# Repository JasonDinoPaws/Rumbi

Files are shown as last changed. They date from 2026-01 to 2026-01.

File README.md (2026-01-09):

This is version 1.0 of Rumbi.

Rumbi comes from the game A hat in time with the soul perpose to give some life to the spaceship. This is trying to give it more of a perpose. This version is slightly buggy since the all the leds need to be ran on sudo but the audio libary will sometimes work.

# Parts
- Pi - https://www.amazon.com/dp/B0899VXM8F?ref=ppx_yo2ov_dt_b_fed_asin_title
- Pi Camera - https://www.amazon.com/dp/B01ER2SKFS?ref=ppx_yo2ov_dt_b_fed_asin_title
- Gearbox Motors - https://www.amazon.com/dp/B098Q1BCX5?ref=ppx_yo2ov_dt_b_fed_asin_title
- Led Strip - https://www.amazon.com/dp/B01MG49QKD?ref=ppx_yo2ov_dt_b_fed_asin_title
- Led Matrix x2 - https://www.amazon.com/dp/B0DGT58PDH?ref=ppx_yo2ov_dt_b_fed_asin_title

# Printing
## Bottom 
- Bottom.stl - 7.5in x 7.5in X 1in
- Ball.stl x3 - .875in

## Motor
- Wheel.stl - Wheel
- Motor Holder.stl - It sits in the center of bottom.stl
- MotorRoof.stl - trying its best to hold the gear motors from comming up
- Lifter and cover.stl - To hold the MotorRoof.stl to Motor Holder.stl 

## Other Interior objects
- Pi.stl - Degined for a Pi 4 and sits on the Lifter and cover.stl
- Battery holder.stl - Combined with x4 Item connectors.stl to connect to Pi.stl
- Item Cover.stl to sit ontop of Battery holder.stl connected by Roof conecters.stl x4
- Amplafiyer.stl, Button.stl, Speaker holder.stl - to fill the space in Item Cover.stl in the order of Amplafiyer.stl, Button.stl, Speaker holder.stl 

## Top
- Top.stl x2 - It's ment to hold the top together with a tight fit, and kindof the walls
- Top exterdor.stl - How the Top.stl stays together
- Innter Top.stl - slides on the Top exterdor.stl
- Cap.stl - to sit on a button  that clsoes the the hold in the Innter Top.stl

## Walls - all are 4.85 in tall
- Fan.stl - the back
- gray.stl x2 - next to fan.stl
- endofblack.stl x2 - next to the gray.stl
- face-L - for the left side of the face
- face-R - for the right side of the face

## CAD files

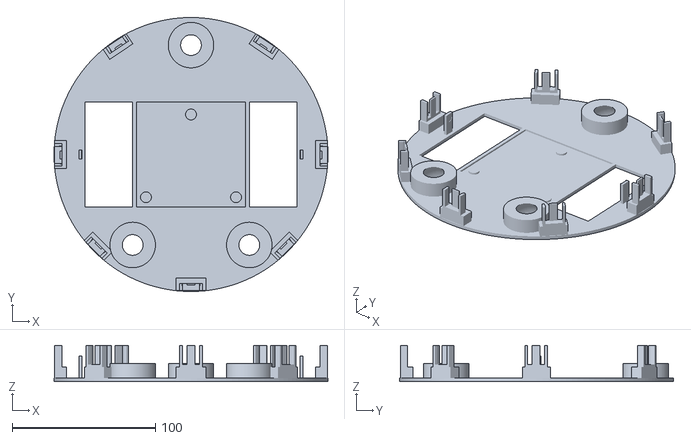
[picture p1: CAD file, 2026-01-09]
Stls/Bottom/Bottom.stl
191.3 x 191.3 x 25.4

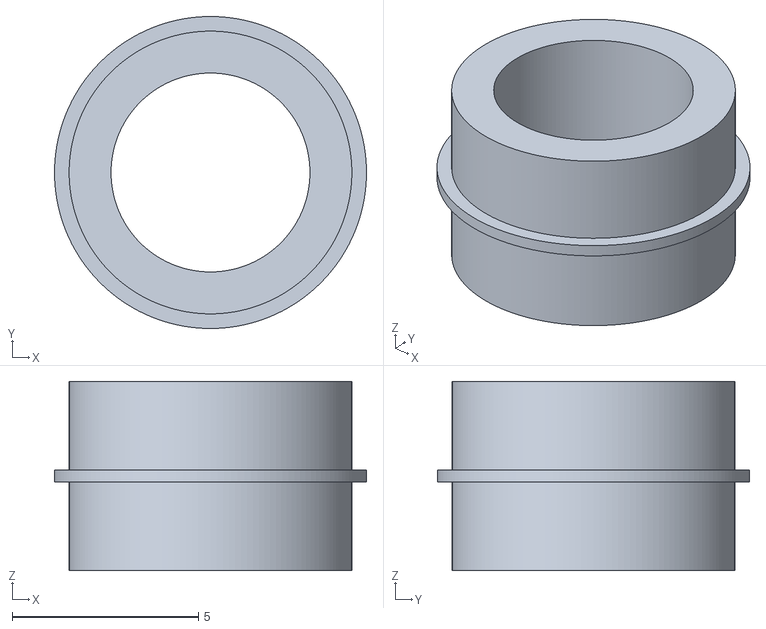
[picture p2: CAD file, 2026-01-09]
Stls/Item connectors.stl
8.38 x 8.38 x 5.08

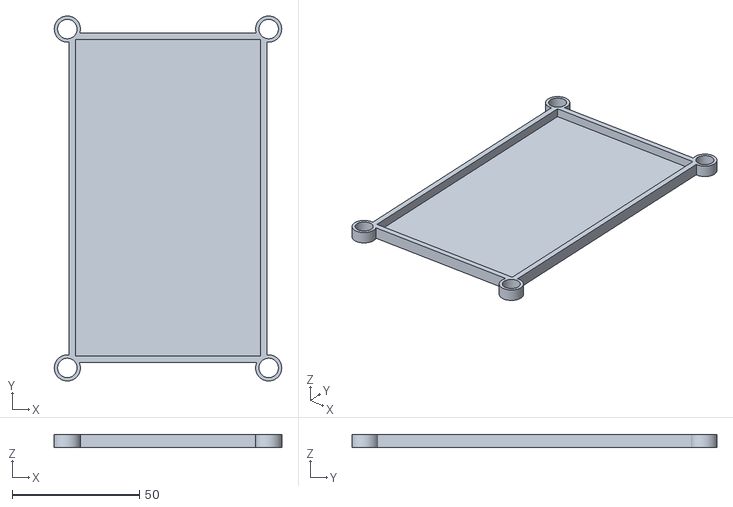
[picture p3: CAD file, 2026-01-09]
Stls/Item Holder/Item Cover.stl
89.3 x 143.3 x 5.08

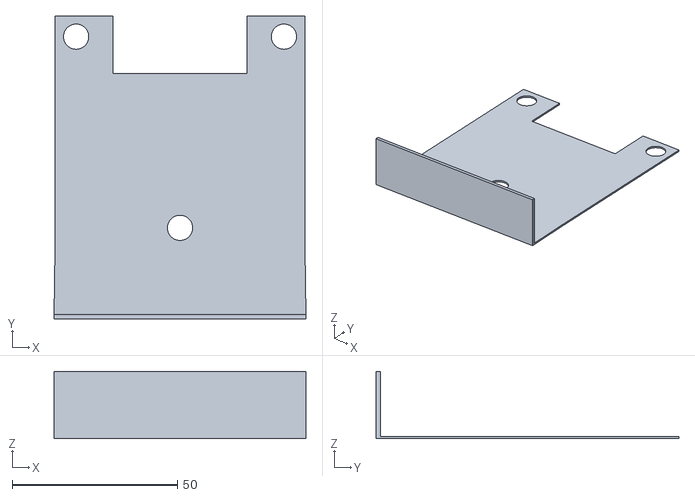
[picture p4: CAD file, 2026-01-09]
Stls/Motor/MotorRoof.stl
76.2 x 91.6 x 20.3

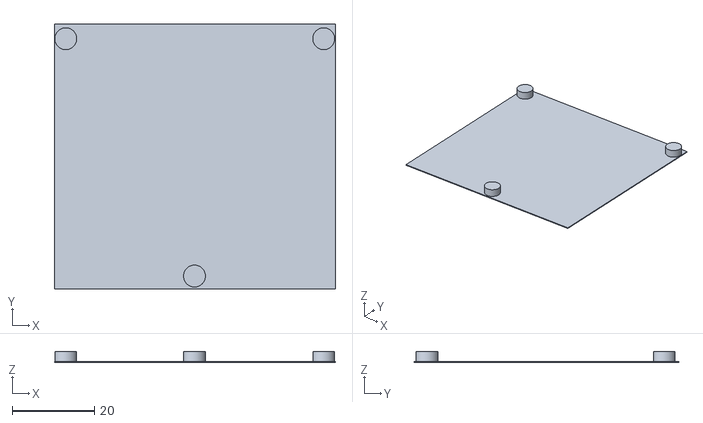
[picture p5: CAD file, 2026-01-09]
Stls/Pi and battery/Defalt big cap.stl
68.5 x 64.5 x 2.79

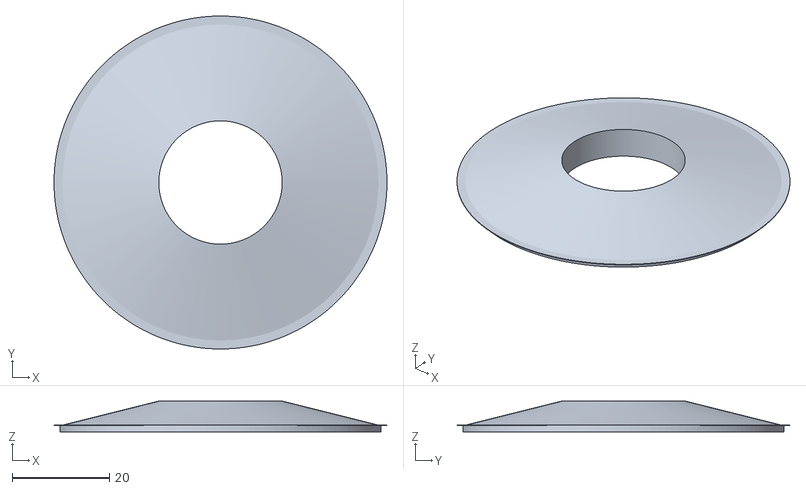
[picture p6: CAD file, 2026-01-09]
Stls/Top/Innter Top.stl
68.6 x 68.6 x 6.35

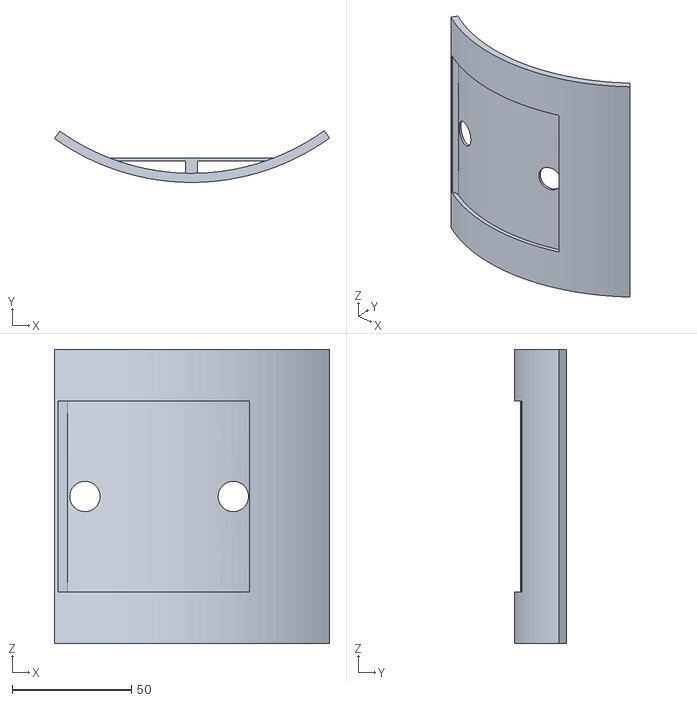
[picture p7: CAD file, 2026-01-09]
Stls/Walls/face-R.stl
115.3 x 21.7 x 123.2

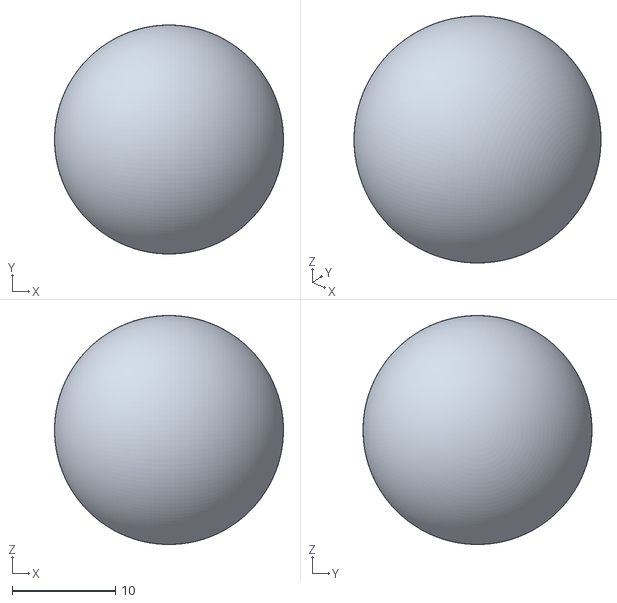
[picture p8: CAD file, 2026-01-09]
Stls/Bottom/Ball.stl
22.2 x 22.2 x 22.2

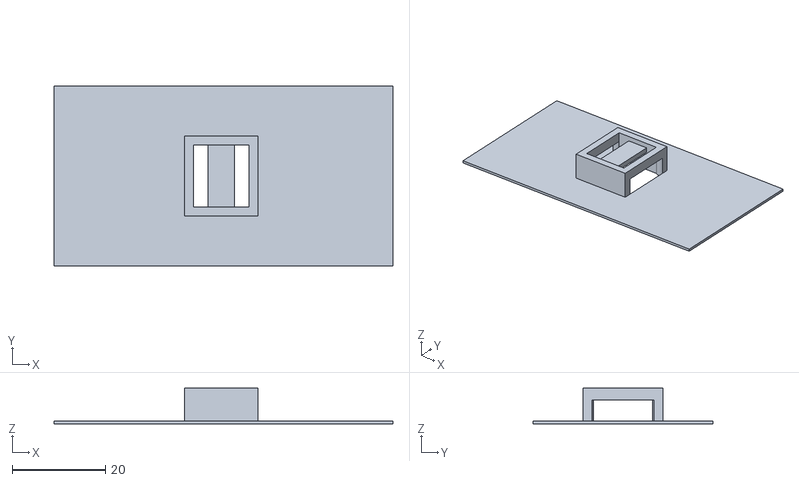
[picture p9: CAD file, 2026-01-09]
Stls/Item Holder/Button.stl
72.6 x 38.6 x 7.62

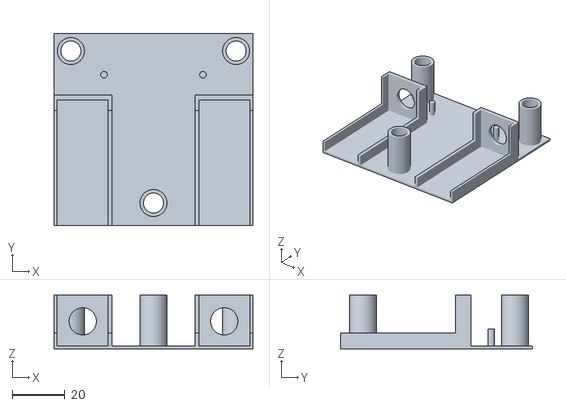
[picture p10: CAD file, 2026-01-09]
Stls/Motor/Motor Holder.stl
75.7 x 73.2 x 20.5

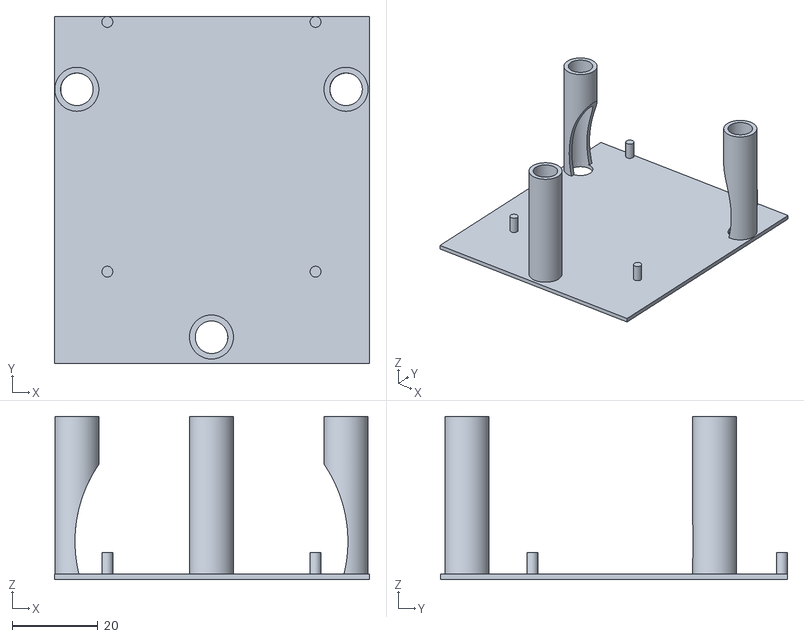
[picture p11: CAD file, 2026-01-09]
Stls/Pi and battery/Pi.stl
73.5 x 81.0 x 38.1

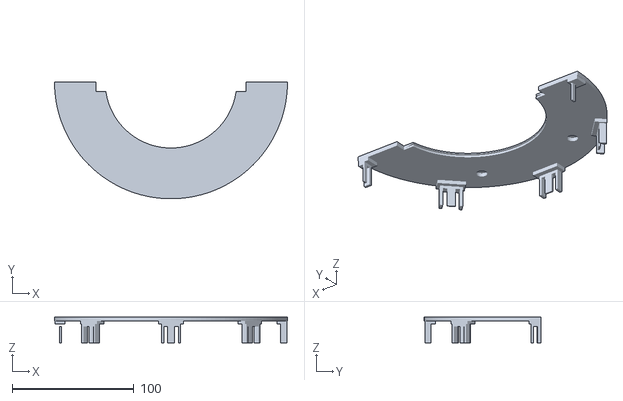
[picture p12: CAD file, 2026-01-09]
Stls/Top/Top.stl
191.3 x 95.6 x 21.0

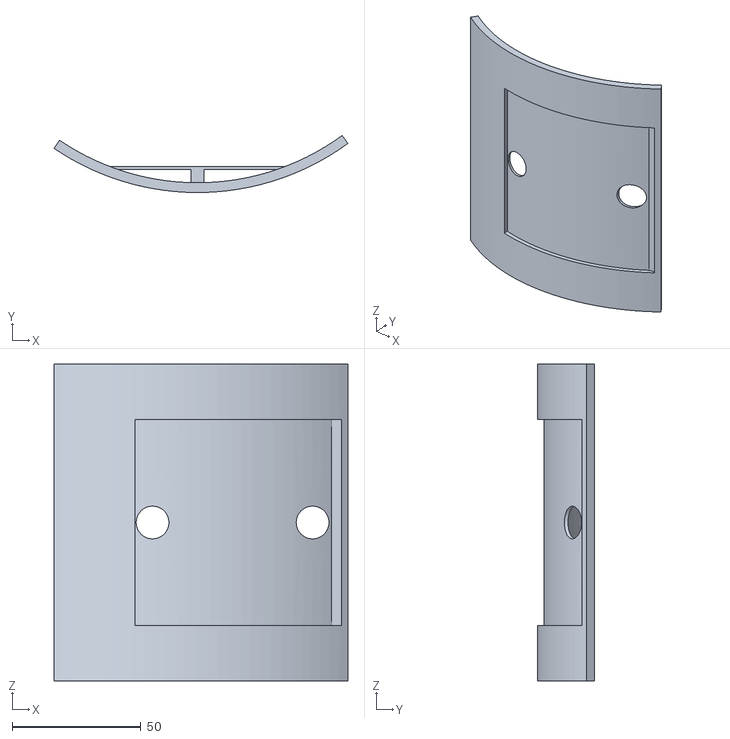
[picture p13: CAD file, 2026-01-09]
Stls/Walls/face-L.stl
114.2 x 22.2 x 123.2

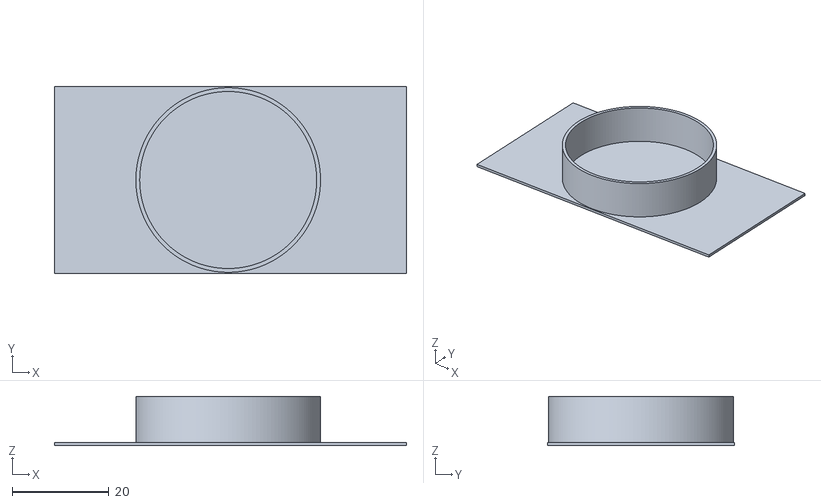
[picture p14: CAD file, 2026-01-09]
Stls/Item Holder/Speaker holder.stl
72.6 x 38.6 x 10.1

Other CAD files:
Stls/Motor/Wheel.stl
Stls/Pi and battery/Battery holder.stl
Stls/Top/Roof conecters.stl
Stls/Walls/gray.stl
Stls/Item Holder/Amplafiyer.stl
Stls/Motor/Lifter and cover.stl
Stls/Top/Cap.stl
Stls/Top/Top exterdor-1.stl
Stls/Walls/Fan.stl
Stls/Walls/endofblack.stl

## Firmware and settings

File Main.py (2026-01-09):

from os import geteuid,listdir,path
from time import sleep,time
from flask import Flask, render_template, Response, request, send_from_directory,jsonify,send_file
from AudioDownload import DownloadAudio
from Enums import *
import cv2
from  threading import Thread
from datetime import datetime


app = Flask(__name__)
isSudo = geteuid() == 0
rpath = "".join(x+"/" for x in __file__.split("/")[:-1])
IsPi = input("IsPi (T,F): ").lower() == "t" and True or False
TakeShots  = input("Save Camera Shots (T,F): ").lower() == "t" and True or False
LoadSounds = input("Load Sounds (T,F): ").lower() == "t" and True or False

if input("Create Log (T,F)").lower == "t":
    import sys
    Log = open(f"{rpath}/Logs/{time()}.txt","+w")
    sys.stdout = Log
    sys.stderr = Log

fileredirects = {
    "Sounds": "Sounds.html",
    "Movement": "Movement.html",
    "Eyes": "Eyes.html",
    "Lights": "Lights.html"
}


def LoadDir(start,subdir=False):
    files = {}
    for x in listdir(start):
        if subdir and path.isdir(f"{start}/{x}"):
            files[x] = LoadDir(f"{start}/{x}",subdir)
        else:
            files[x] = f"{start}/{x}"
            
    return files

def FindFile(tab,fpath):
    if fpath[0] == "/":
        fpath = fpath[1:]

    np =  fpath.split('/',1)
    ind = np[0] in tab

    if ind and isinstance(tab[np[0]], dict):
        return FindFile(tab[np[0]],np[1])
    elif ind:
        return tab[np[0]]
    else:
        return False
    
import Sounds
if IsPi:
    from Camera import Camera
    from MotorController import Controller
    C = Camera(820,616,fl=False)
    M = Controller(17,27,22,23)   
    if isSudo:
        from Leds import Matrix,Strip
        Ma = Matrix(rows=8,cols=8,rotation=180)
        sleep(.005)
        Ma2 = Matrix(rows=8,cols=8,rotation=180,flip=True)
        sleep(.005)
        S = Strip(count=28)
        S.PlayAnimation(Animations.Random("Loading"))
        Ma.ShowImage("Eyes/loading.png")
        Ma2.ShowImage("Eyes/loading.png")



Websitefiles = listdir(rpath+"templates")#LoadDir(rpath+"templates",True)
Imagefiles = LoadDir(rpath+"Images",True)


#Set Up
@app.route('/')
def index():
    return render_template('index.html') 


@app.route('/<filename>')
def website_files(filename):
    if filename in fileredirects:
        filename = fileredirects[filename]

    if filename in Websitefiles:
        if filename[-5:] == ".html":
            return render_template(filename) 
        elif filename[-4:] == ".txt":
            return Response(open(f"{rpath}templates/{filename}","r").read(), mimetype='text/plain')
        
        return send_file(f"{rpath}templates/{filename}", as_attachment=True)
    return None

@app.route('/Images/<path:filename>')
def iamge_files(filename):
    file = FindFile(Imagefiles,filename)
    if file:
        return send_file(file, as_attachment=True)
    return jsonify("Failed")


def gen(inst):
    while True:
        sleep(.05)
        frame=None
        if inst == "camera":
            frame = C.frame

        if frame != None:
            yield b'--frame\r\n' b'Content-Type: image/png\r\n\r\n' + frame + b'\r\n'


@app.route("/get/<path:filename>")
def getinfo(filename:str):
    objtype,inst = filename.split("/",1)
    if objtype == "queue":
        if inst == "Sounds": 
            return  [x[0:2] for x in Sounds.AudioQueue]
        elif inst == "Motor" and IsPi:
            return M.Queue
        else:
            return {}
    elif objtype == "lights":
        file = None
        match inst:
            case "head":
                if isSudo and IsPi and "S" in globals():
                    file = FindFile(Imagefiles,str(S.animation).replace(".","/")+".gif")
                if not file:
                    file = FindFile(Imagefiles,"Animations/Off.gif")

            case "face":
                if isSudo and IsPi and "Ma" in globals():
                    file = FindFile(Imagefiles,str(Ma.animation))
                if not file:
                    file = FindFile(Imagefiles,"Eyes/idle.png")

        return send_file(file, as_attachment=True)
    elif objtype == "video":
        return Response(gen(inst), 
                                mimetype='multipart/x-mixed-replace; boundary=frame')
    return

@app.route("/chng/<path:filename>")
def Change(filename:str):
    typ,inst = filename.split("/",1)
    match typ:
        case "head":
            if "S" in globals():
                S.StopAnimation()
                if inst == "Full":
                    S.ColorAll()
                elif inst in Animations.__members__:
                    S.PlayAnimation(Animations[inst])
        case "face":
            if "Ma" in globals():
                if FindFile(Imagefiles,f"Eyes/{inst}.png"):
                    Ma2.ShowImage(f"Eyes/{inst}.png")
                    Ma.ShowImage(f"Eyes/{inst}.png")

    return "No returned"

# Wheels
@app.route("/move/<action>/<dur>")
def move(action:str,dur:float):
    action = action.split(",")
    dur = float(float(dur))
    if IsPi:
        if len(action) > 1:
            M.Action(int(action[0]),dur/2)
            M.Action(int(action[1]),.24)
            M.Action(int(action[0]),dur/2)
        elif int(action[0]) == -1:
            M.Reset()
        else:
            M.Action(int(action[0]),dur)
    return jsonify(result="sent action")

# Sound
@app.route("/sound/")
def getounds():
    return [x for x in Sounds.loaded.keys()]

@app.route("/sound/play/<name>")
def playsound(name:str):
    name = name.replace("⠀","/").replace("‎","?")
    
    if name.startswith("text:"):
        print(name[5:])
        return jsonify("no")
    elif name.startswith("http"):
        name = DownloadAudio(name)

    Sounds.Playsound(name)
    return jsonify(result=f"Played")

def Updateobjs():
     nt = 0
     while IsPi:
        time = datetime.now()
        C.get_frame()
        if TakeShots and time.second %2 == 0 and time.second != nt:
            nt = time.second
            with open(f"{rpath}/map/{time}.jpg","+wb") as file:
                file.write(C.frame)
            cv2.imwrite(f"{rpath}/map/{time}.jpg",C.frame)


if __name__ == "__main__":
    if LoadSounds:
        Sounds.LoadSounds()
    input("Start?")
    if IsPi and isSudo:
        Ma2.ShowImage("Eyes/idle.png")
        Ma.ShowImage("Eyes/idle.png")
        S.StopAnimation()
        S.ColorAll()
    if LoadSounds:
        Sounds.Playsound("Opening.wav")
        Sounds.random(rpath+"Sounds/OpeningSFX")
    
    Thread(target=Updateobjs).start()
    
    app.run(host='0.0.0.0', debug=False, port=isSudo and "80" or "5000", threaded=True)

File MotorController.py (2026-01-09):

import RPi.GPIO as GPIO
from time import sleep
from threading import Thread

class Controller:
    def __init__(self, p1:int,p2:int,p3:int,p4:int,actions:list[int]=[[1,0,1,0], [0,1,1,0], [0,1,0,1], [1,0,0,1]]):
        self.pins = [p1,p2,p3,p4]
        self.actions = actions
        self.motion = 0
        self.Queue = []
        GPIO.setmode(GPIO.BCM)
        for x in self.pins:
            GPIO.setup(x, GPIO.OUT)
        self.Reset()
        pass

    def Reset(self):
        self.motion = 0
        self.Queue = []
        for x in self.pins:
            GPIO.output(x, False)
    
    def RunQueue(self):
        self.motion = 1
        while len(self.Queue) > 0:
            a,d = self.Queue.pop(0)
            print(a,d)

            for n in range(len(self.actions[a])):
                GPIO.output(self.pins[n], self.actions[a][n])
            sleep(d)
        self.Reset()


    def Action(self,action:int,dur:float):
        if action >= 0 and action < len(self.actions) and dur > 0 and dur < 10:
            self.Queue.append((action,dur))

            if self.motion == 0:
                Thread(target=self.RunQueue,daemon=True).start()
